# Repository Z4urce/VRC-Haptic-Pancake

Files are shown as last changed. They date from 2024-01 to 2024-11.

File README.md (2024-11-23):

# VRChat Haptic Pancake (for trackers)
A dirt cheap solution to enable haptic feedback on the Vive trackers in VRChat and Resonite.

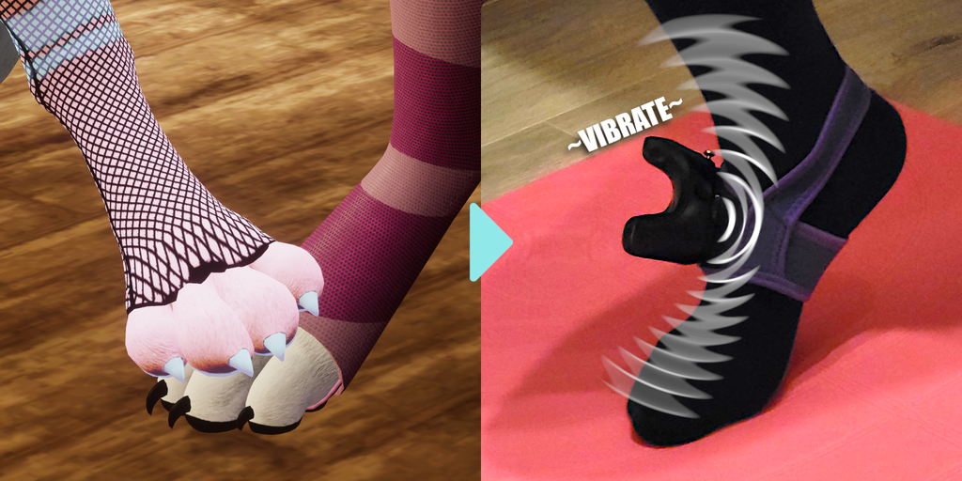
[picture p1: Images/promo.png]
[](https://youtu.be/c1JQpJwJ7_c)

# Contact

Curious about the development? Have any questions? Join the discord!



# How to make
[> Check out the Wiki for a full guide! <](https://github.com/Z4urce/VRC-Haptic-Pancake/wiki)

# Planned Features
- Support for DIY haptic devices through serial connection

# Frequently Asked Questions
- Will this harm my tracker in any way?
   - The tracking capabilities of your tracker should not get harmed at all. In case of an unexpected high load the output pin of your tracker might get fried out. That only means that in the worst case scenario you won't be able to use a vibration function on that particular tracker anymore. However after two weeks of intensive testing on my own trackers I experienced no problems whatsoever. I'll update this page if anything changes.
- Will this affect my tracking?
   - Since I implemented the vibration pattern system, it barely affects the tracking. But it still depends on the selected pattern. For example You should experience minor to no drifting with the 'Linear' one.
- Can I put the tracker elsewhere after setting up my avatar?
   - Yes. None of the trackers are permanently linked to any parts of your avatar. In fact you can even hotswap them. Just ensure you are using the right parameters in the bridge app. 
- How does this work with non-Vive trackers?
   - The software side support is guaranteed by the Haptic Pancake Bridge app. Every SteamVR compatible tracker will be recognized and external device support is imminent.
   - The hardware side is a bit more complicated:
       - For Tundra trackers you will need a custom PCB from here: [Tundra Tapper](https://github.com/nkotech/Tundra-Tapper)
       - Controllers that has been re-programmed into trackers will just work as they have haptics built in.
       - Anything else should only work if the hardware respects the SteamVR api and has built in haptics or IO to attach one.

# Support the project
<a href='https://ko-fi.com/Z4urce' target='_blank'>Buy Me a Coffee at ko-fi.com

# Special Thanks
- @BubblegumFoxxo (For helping in the testing and debugging)
- @vulp_vibes (for giving me the idea)
- @digitalf0x (for support and contributions)

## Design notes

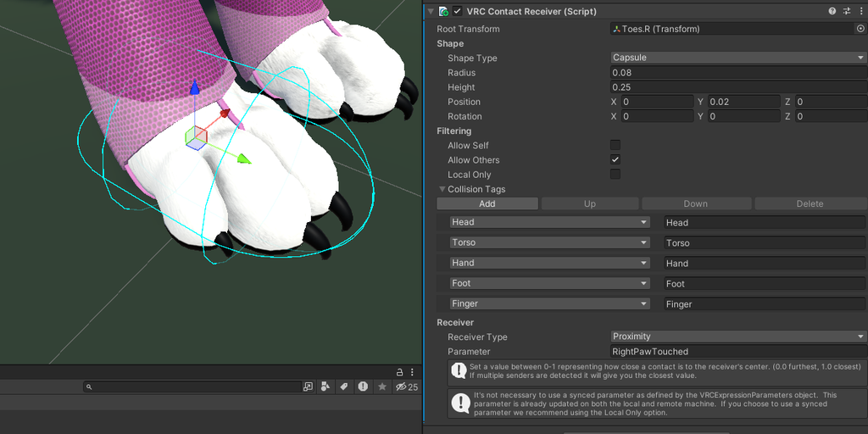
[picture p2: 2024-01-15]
Images/unity.png

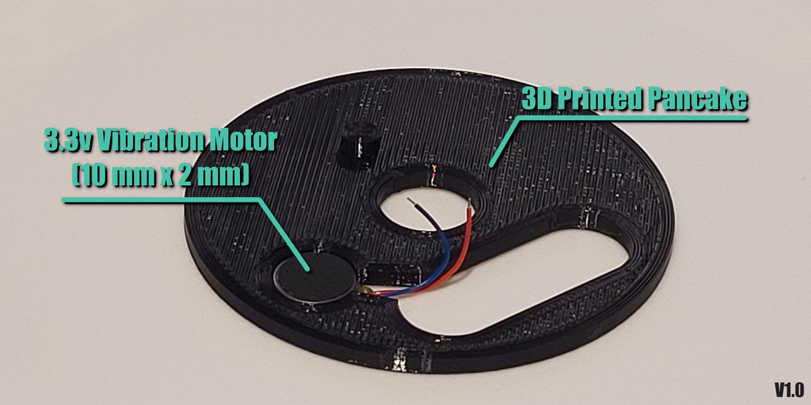
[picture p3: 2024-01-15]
Images/pancake.png

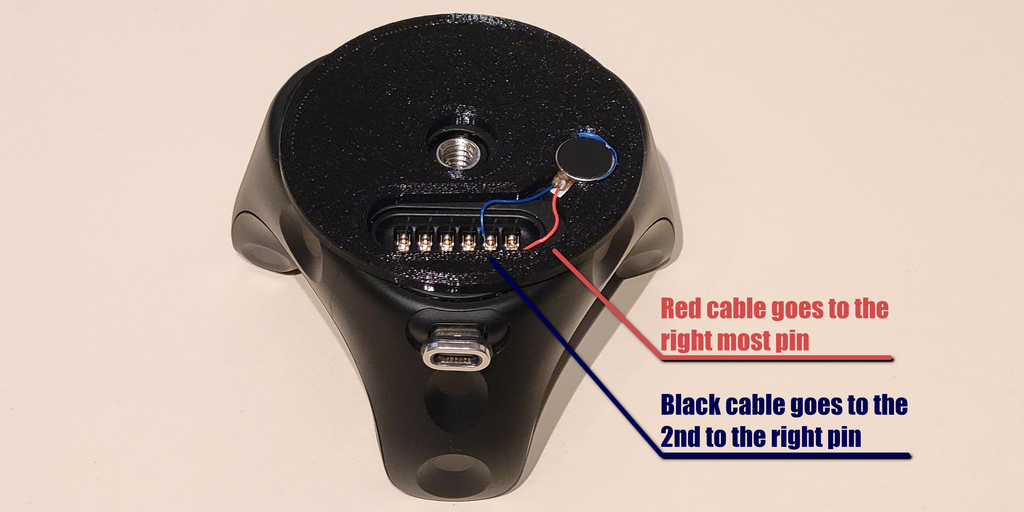
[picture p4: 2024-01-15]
Images/cable.png

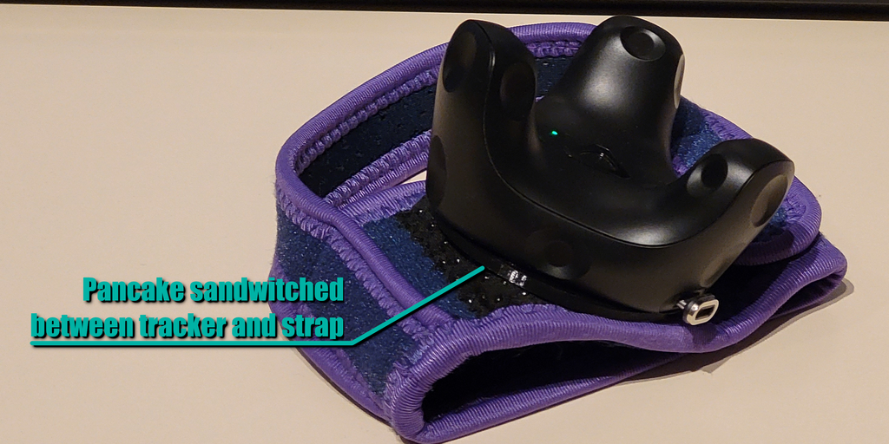
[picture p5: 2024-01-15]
Images/sandwitch.png

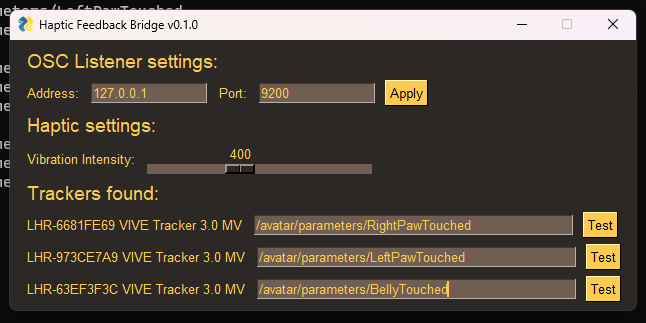
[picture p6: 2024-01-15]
Images/bridgeapp.png

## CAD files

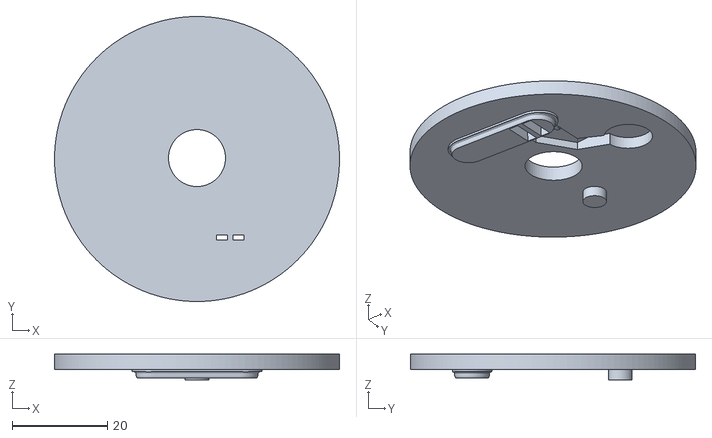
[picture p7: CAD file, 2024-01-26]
3DPrintableFiles/haptic_pancake_v2.0_M3.stl
60.0 x 60.0 x 5.45

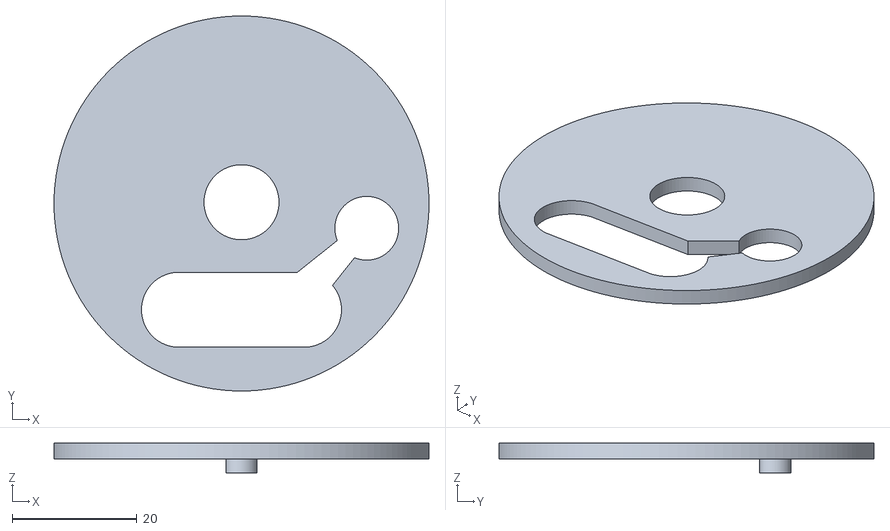
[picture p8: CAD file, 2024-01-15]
3DPrintableFiles/haptic_pancake_v1.0.stl
60.0 x 60.0 x 4.75

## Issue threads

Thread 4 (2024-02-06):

Enclosure for Tundra Tracker's IO Expansion board

digitalf0x, 2024-02-06:
## In brief
* Tundra Tracker's [IO Expansion Board](https://tundra-labs.com/products/tundra-tracker-io-expansion-board ) adds haptic options, but lacks the enclosure
   * Tundra Labs mentions [needing to customize the 3D model of the base](https://twitter.com/Tundra_Labs/status/1486802927293505536 ) to fit the haptic actuator inside
   * My 1st IO board order came with a haptic actuator, not soldered - not sure if this is standard policy

## Details
While it's possible to wire up the haptic actuator on the side and tape it somewhere, it'd be nice to integrate this with the Tundra Tracker enclosure directly.  At the time of my order, Tundra Labs shipped the right haptics actuator with the IO Expansion Board, I'd just need to solder it on.

Looking around, I've not found any existing shared 3D printable enclosures that could hold the haptics actuator.

----

I noticed your hidden `Ongoing Research` wiki page mentions this is under consideration.  If there's anything I can do to help that research, let me know.  I'm handy with electronics, though I lack a 3D printer (I can use services such as Craftcloud if needed).

This project *seems* to not be too Windows-centric, either, so I'd be happy to try to help with getting it working on Linux as part of this.

Z4urce, 2024-02-13:
Hello!
I have a discord server for research and development. [Feel free to join us!](https://discord.gg/DEWbQHqbRS)

A member of it already made the tundra's haptics work with the pancake bridge software. (With the same ERM vibration motor I recommended for the pancake)

Unfortunately I'm unable to design an enclosure for them as I don't own any. But I can help you with that if you'd like to join our cause :)

And about Linux support... I made sure the software is as multi-platform as it can be :3

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

digitalf0x, 2024-02-14:
Ah, awesome!  I imagine the enclosure will be a bit different using the haptics motor Tundra unexpectedly included with my IO board (it looks like the Switch Joycon form factor they suggest in the description, maybe it's now standard?), but that's something we can work out.

I have been pretty busy, so it will be some time until I can contribute measurements/testing/etc.  But I'll at least join the guild, and I appreciate the Linux consideration - I know it's niche to VR with Tux, but there are dozens of us :P

(I got your poke over on that IRC server, too - no worries, I got the email notification.  Though I appreciate your enthusiasm and effort to navigate a platform so few people use nowadays :sweat_smile: )

digitalf0x, 2024-03-05:
*Documenting this publicly for those following here, not on the Discord guild:*

Nearly everything works on Linux, just using the `python3 -m trace --count --coverdir=/dev/null BridgeApp/main.py` launch method to work around the segfault I experience (I updated my prior comment).

Unfortunately, Tundra Trackers seem to implement [Valve's deprecated `TriggerHapticPulse`](https://github.com/ValveSoftware/openvr/blob/v2.2.3/headers/openvr.h#L2431-L2433 ) in a way that fails to work with how VRC Haptic Pancake sends haptic pulses.

The problem might be as [described on the Steam Community forums](https://steamcommunity.com/app/358720/discussions/0/405693392914144440/ ):
> The parameter you pass into TriggerHapticPulse is measured in microseconds, with the max value (in my tests) being 3999, which is 4ms - each frame at 90Hz is 11ms long.  Because of this, if you're pulsing each frame, the effect of pulse length is felt subjectively as vibration strength.

Dropping the intensity multiplier to `10` and boosting `app_runner.py`'s `self.interval_ms = 50  # millis` to `5` milliseconds results in a partially working vibration, though the Tundra Tracker occasionally doesn't respond, blinking red, so I think I might be sending invalid commands.

(It didn't blink red when I previously put the `__pulse()` function into a while true: loop to cause it to vibrate near continuously, so I don't think it's an over-current situation.)

I'll keep looking into this as I have time to investigate.  [Maybe the `IVRInput` methods](https://github.com/ValveSoftware/openvr/blob/v2.2.3/headers/openvr.h#L5216-L5218 ) would work more consistently… if it's supported by Vive/Tundra Trackers (I recall hearing something about it only working for actual full-blown controllers, not trackers).

digitalf0x, 2024-03-08:
Doing some *very rough* experimentation, it seems like the Tundra Tracker stops responding for a short period of time if it's given too many `triggerHapticPulse()` commands (e.g. quicker than 5 ms delay), while at the same time it won't really pulse for longer than 5 ms either (possibly 3999 µs as in the Steam Community forums post linked in my prior comment).

**I do not recommend implementing the following in VR Haptic Pancake yet**, this is merely something kind of functional that I got with ~15 minutes of poking things:

Tweak to `BridgeApp/app_runner.py`:
```diff
--- BridgeApp/app_runner.py
+++ BridgeApp/app_runner.py
@@ -1,3 +1,3 @@

-        self.interval_ms = 50  # millis
+        self.interval_ms = 5  # millis
         self.interval_s = self.interval_ms / 1000  # seconds
```

And the `config.json`, prettified:
```json
{
  "version": 1,
  "server_type": 0,
  "server_ip": "127.0.0.1",
  "server_port": 9001,
  "pattern_config_list": [{
    "pattern": "Throb",
    "str_min": 0,
    "str_max": 80,
    "speed": 4
  }, {
    "pattern": "Linear",
    "str_min": 40,
    "str_max": 80,
    "speed": 16
  }],
  "tracker_config_dict": {
    "LHR-[serial-here]": {
      "enabled": true,
      "address": "/avatar/parameters/HapticsTouchWaist",
      "multiplier_override": 9.0,
      "pattern_override": "None",
      "battery_threshold": 20
    }
  },
  "tracker_to_osc": {}
}
```

This ensures that `target_ovr.py` doesn't send a pulse longer than 5 ms (might need to be 3999 µs?), as longer values seem to not actually result in longer vibration.  The below edit to `target_ovr.py` confirms this by printing a warning if you exceed that threshold.

```python
    def __pulse(self, index, pulse_length: int = 200):
        if self.is_alive():
            self.vr.triggerHapticPulse(index, 0, pulse_length)
            # HACK: test spacing out pulses
            #pulse_max_amount = 3999
            pulse_max_amount = 5000
            #sleep_min_delay = pulse_max_amount / 1000000
            #sleep_min_delay = 5000 / 1000000
            if pulse_length > pulse_max_amount:
                print("PULSE LENGTH > " + str(pulse_max_amount) + ": " + str(pulse_length))
            #while pulse_length > 3999:
            #    self.vr.triggerHapticPulse(index, 0, pulse_max_amount)
            #    pulse_length -= pulse_max_amount
            #    time.sleep(sleep_min_delay)
            #if pulse_length > 0:
            #    self.vr.triggerHapticPulse(index, 0, pulse_length)
            #    time.sleep(sleep_min_delay)
```

I got the "Identify" command to meaningfully work by uncommenting the lines to repeatedly call `triggerHapticPulse()` (and adding `import time` at the top), but doing that breaks elsewhere because the `sleep()` halts everything else.

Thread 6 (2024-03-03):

VRCOSC Modular Support

TypicalZedF, 2024-03-03:
Essentially, there is this application called [VRCOSC](https://github.com/VolcanicArts/VRCOSC). "VRCOSC is intended to act as a wrapper around VRChat's OSC system to make creating OSC programs easier, provide interfaces for other APIs and frameworks that might be useful to an OSC project, and act as a centralized source for useful OSC programs so that a user will only need to download a single application."

Essentially, I'm requesting that you port the software to work with this application so that instead of users needing to have a different application for everything, all OSC stuff including your haptic pancakes would be utilized through one application making it easier for everyone! I'm curious to see if you'll support the application as it has large numbers of users. They have documentation on how to make [Modules here](https://github.com/VolcanicArts/VRCOSC/wiki/Module-Creation).

Z4urce, 2024-03-05:
This projects will stay as a standalone application to ensure the compatibility across platforms, devices and environments.

TypicalZedF, 2024-04-25:
The Haptic Pancakes use a standard haptics system. Even Space Calibrator can cause the trackers to vibrate. I'd think it's possible to just adopt this myself to VRCOSC, and for those that wish to use it instead opposed to the python UI may.

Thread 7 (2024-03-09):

STL Print for Vive Ultimate Trackers?

JessPratson2, 2024-03-09:

Z4urce, 2024-03-14:
Waiting for a donation of Vive Ultimate trackers so I can make an STL for them as well.

TrademarkPoIicy, 2024-03-17:
I see where you are coming from needing the tracker to make sure the STL fits properly around the housing. If I had the extra money I would donate a set of trackers to you but I do not sadly. I would also like to state I am not good at CAD took one year in middle school but I can be relentless. So I have slowly started working on making housing for a haptic motor plus an easy way of connecting/disconnecting wires using screws and pogo pins combined with the ability to clip the plate that screws on a strap on the back of the tracker making there be pressure for the Pogo pins to pop into place. There is also a stl available on Vives website of the tracker. On another note, I'd like to thank you for the work that you have put in on the project and please keep up the great work.

TrademarkPoIicy, 2024-04-18:
Well this took longer than I thought it would but here it is...

[Vive_Ultimate_Tracker_Screw-On-Mount_Haptic-Pancake_ External-Wire-Crimping.zip](https://github.com/Z4urce/VRC-Haptic-Pancake/files/15021630/Vive_Ultimate_Tracker_Screw-On-Mount_Haptic-Pancake_.External-Wire-Crimping.zip)

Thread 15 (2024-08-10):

Migrate to IVRInput's haptic Actions and/or consider OpenXR?

digitalf0x, 2024-08-10:
# About that `IVRInput`…

This is the supported, modern way forward.

* Allows for frequency modulation
   * Even with ERMs instead of LRAs, offers a slightly adjustable haptics feel on Tundra Trackers
* Allows Steam to automatically map Vive/Tundra/etc Trackers with given SteamVR roles (e.g. Chest, Left Foot)
   * Haptic Pancake would just be mapping from e.g. "Chest tracker" to `/avatar/parameters/something_here`
* Solves the Tundra Tracker issue with the legacy haptics pulses being cut off, requiring 4 ms loops
* As part of this, we'll want a `.vrmanifest` file which will make the Bridge App auto-start with SteamVR, too

But.. it is an involved change.

I still don't get why `lighthouse_console`'s `haptic2` command can use the new haptics API without the need for the entire SteamVR Actions system - if we could simply copy that, then Haptic Pancake itself would need almost no changes.

**Further research on `triggerHapticVibrationAction` and how the Lighthouse console uses it is needed.**

This is a large enough project we may want to make this a v2 of Tundra Tracker support, or even a v2 of the entire Bridge App.

Considering Valve is pushing SteamVR towards OpenXR (an actually independent standard) as the replacement for OpenVR (Valve's own standard), perhaps OpenXR will provide another path forward?  It looks like [OpenXR uses the same rebindable Action system, though](https://registry.khronos.org/OpenXR/specs/1.0/man/html/xrApplyHapticFeedback.html ).

## Using `lighthouse_console`

With **SteamVR open** and your **headset connected to your PC**…

### Launching console

#### Linux

Run as your normal user:
```
$HOME/.local/share/Steam/steamapps/common/SteamVR/tools/lighthouse/bin/linux64/lighthouse_console
```

#### Windows

May need to run as administrator:
```
C:\Program Files (x86)\Steam\steamapps\common\SteamVR\tools\lighthouse\bin\win32\lighthouse_console.exe
```
(See [this HTC thread](https://forum.htc.com/topic/7413-how-to-unpair-all-controllers-peripherals-while-troubleshooting/ )

### Examples

#### Haptics help
```
lh> help
[…]
haptic [<duration_us>] [<interval_us>] [<repeat_count>] Trigger haptic pulse
haptic2 [<frequency_hz>] [<duration_ms>] [<amplitude_percent>]  Trigger haptics
[…]
```

#### Legacy API
`triggerHapticPulse()`

Some long duration (4000µs duration, 4000µs interval, 100× repeat):
```
lh> haptic 4000 4000 100
```

#### Modern API
`triggerHapticVibrationAction()`

400 Hz for 4 seconds:
```
lh> haptic2 400 4000
```

## SteamVR OpenVR API
### Legacy API (in use now)

```python
    def triggerHapticPulse(self, controllerDeviceIndex, axisId, durationMicroSec: int) -> None:
        """
        Trigger a single haptic pulse on a controller. After this call the application may not trigger another haptic pulse on this controller
        and axis combination for 5ms. This function is deprecated in favor of the new IVRInput system.
        """
        […]
```

**OpenVR says the duration is in microseconds, NOT milliseconds!**

Vive Trackers are doing something wrong.  (Perhaps they were built to an older spec, and HTC didn't want to break backwards compatibility for their enterprise customers?)  Tundra Trackers, Index Wands, etc are doing things correctly.

Tundra Trackers do have a problem with cutting off haptic pulses longer than about 4000 microseconds, though.

### Modern API (`IVRInput`)

```python
    def triggerHapticVibrationAction(self, action, startSecondsFromNow: float, durationSeconds: float, frequency: float, amplitude: float, restrictToDevice) -> None:
        """Triggers a haptic event as described by the specified action"""
        […]
```

[SteamVR now makes everything - **including haptics!** - rebindable with SteamVR Input 2.0, as per the Action manifest](https://github.com/ValveSoftware/openvr/wiki/Action-manifest ).

Haptic Pancake will no longer handle mapping to specific trackers.  This is handled by SteamVR's own UI with assigning roles to trackers.

This should allow changing tracker bindings inside SteamVR and when Haptic Pancake isn't running.

This involves a lot of haptics vibrations:
> vibration - The action is a output haptic vibration. Include one of these per type of haptic output in your application so they can be bound to different output devices if the user has them available. Examples include haptics due to firing a gun (that would usually be bound directly to a controller) or haptics from getting shot (which could be bound to a feedback vest worn on the chest).

And I think this is looking at…
1.  `def setActionManifestPath(self, actionManifestPath: str) -> None:` which will need generated according to the Valve wiki page
2.  `def getActionHandle(self, actionName: str):` on tracker load
3.  `def triggerHapticVibrationAction(self, action, [...]) -> None:` inside the Bridge App haptics loop

And to allow binding when Bridge App isn't running, and to have SteamVR auto-start the Bridge App, then we need a `.vrmanifest` file, like how WlxOverlay-S creates it - see below.

#### Other context

The whole [action manifest is the route VRCOSC went, though they're only handling controllers](https://github.com/VolcanicArts/VRCOSC/blob/main/VRCOSC.Resources/OpenVR/action_manifest.json ).

[VRC-OSC-Manager](https://github.com/DASPRiD/vrc-osc-manager ) looked interesting initially as it supports both Linux and Windows and allows multiple plugins to use one OSC input, but that entirely skips VR manifests.

#### Example config files

Adapted from [Valve's documentation](https://github.com/ValveSoftware/openvr/wiki/Action-manifest#action-manifest-file-format).
**`BridgeApp/hp_actions.json`:**
```json
{
  "default_bindings": [
   {
      "controller_type": "some_controller",
      "binding_url": "hp_bindings_fbt_trackers.json"
   }
  ],
  "actions": [
    {
      "name": "/actions/hp_haptics/out/chest",
      "requirement" : "optional",
      "type": "vibration"
    },
    {
      "name": "/actions/hp_haptics/out/foot_left",
      "requirement" : "optional",
      "type": "vibration"
    }
  ],
  "action_sets": [
    {
      "name": "/actions/hp_haptics",
      "usage": "leftright"
    }
  ],
  "localization" : [
   {
       "language_tag": "en_us",

        "/actions/hp_haptics" : "Haptics",

        "/actions/hp_haptics/out/chest" : "Touch near Chest",
        "/actions/hp_haptics/out/foot_left" : "Touch near Left Foot",

    }
  ]
}
```

Adapted [from WlxOverlay-S `actions_binding_vive.json`](https://github.com/galister/wlx-overlay-s/blob/main/src/res/actions_binding_vive.json ).
**`BridgeApp/hp_bindings_fbt_trackers.json`:**
```json
{
   "action_manifest_version" : 0,
   "app_key" : "galister.wlxoverlay-s",
   "bindings" : {
      "/actions/default": {
         "haptics": [
            {
               "output": "/actions/hp_haptics/out/chest",
               "path": "/user/[path for SteamVR's chest tracker role, e.g. 'hand/left']/output/haptic"
            },
            {
               "output": "/actions/hp_haptics/out/foot_left",
               "path": "/user/[path for SteamVR's left foot tracker role, e.g. 'hand/left']/output/haptic"
            }
         ]
      }
   },
   "category" : "steamvr_input",
   "controller_type" : "TODO_vive_controller",
   "description" : "Ver1",
   "interaction_profile" : "",
   "name" : "Haptic Pancake configuration for Full Body Trackers",
   "options" : {
      "mirror_actions" : false,
      "simulated_controller_type" : "none"
   },
   "simulated_actions" : []
}
```

Adapted [from WlxOverlay-S `openvr/manifest.rs`](https://github.com/galister/wlx-overlay-s/blob/main/src/backend/openvr/manifest.rs ).
**`BridgeApp/haptic_pancake.vrmanifest`:**
```json
{
    "source" : "builtin",
    "applications" : [
            {
                "app_key" : "z4urce.vrc-haptic-pancake",
                "launch_type" : "binary",
                "binary_path_linux" : "PATH/TO/hapticpancake",
                "binary_path_windows" : "PATH\\TO\\hapticpancake.exe",
                "is_dashboard_overlay" : false,
                "strings" : {
                    "en_us": {
                        "name" : "Haptic Pancake",
                        "description" : "A cheap solution to enable haptic feedback on full body trackers in OSC compatible games.",
                    }
                }
            }
        ]
    }
```

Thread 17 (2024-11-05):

Haptic Pancake Hotfix (v0.5.3) 's identify button doesn't seem to work correctly for TundraTracker. But latest source works correctly.

xlwnya, 2024-11-05:
I tried latest release (v0.5.3) binary and I found it's identify button doesn't vibrate the tundra tracker.

I don't know why because I tried to run Haptic Pancake from source (2024-08-20) before and it vibrate the tundra tracker correctly.

Is some regression happened to release?

I tried latest commit (011bff28b68d336e4789825fe75800894297c968) and it also works correctly.

v0.5.3 vibrates the tundra tracker 500us
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

latest source vibrates the tundra tracker 500ms
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

xlwnya, 2024-11-05:
Here is diff of my local source. (I use Japanese version of Windors and this adhoc patch fixes character set problem (My Windows can't display the "⚫" in console)
And I think this diff is not related to the problem of TundraTracker support.
```
 BridgeApp/app_gui.py | 2 +-
 1 file changed, 1 insertion(+), 1 deletion(-)

diff --git a/BridgeApp/app_gui.py b/BridgeApp/app_gui.py
index aeadc12..3aac17b 100644
--- a/BridgeApp/app_gui.py
+++ b/BridgeApp/app_gui.py
@@ -101,7 +101,7 @@ class GUIRenderer:
         return sg.Text('', font=('AnyFont', 1), auto_size_text=True)

     def tracker_row(self, tracker_id, tracker_serial, tracker_model):
-        string = f"⚫ {tracker_serial} {tracker_model}"
+        string = f"{tracker_serial} {tracker_model}"

         dev_config = self.config.get_tracker_config(tracker_serial)
         address = dev_config.address
```

digitalf0x, 2024-11-13:
I'm not sure, but I think there might be something missing from the release build uploaded to GitHub.  A friend I was helping also had the issue of the wrong pulse length.

If you can capture Python's console output on Windows, you can look for `Using 4.0 ms pulse limit workaround for […]` - if that's not there, the code isn't working either.

The commit in question is [[Update] Support Tundra Tracker with timing quirks](https://github.com/Z4urce/VRC-Haptic-Pancake/commit/8f5b5ba26c8eb711b4ec529e0dc791275b489a1b ).

xlwnya, 2024-11-13:
New release "Haptic Pancake (v0.6.0a)" vibrate the tundra tracker correctly!
It's fixed.
Thank you!

Closed 2024-11-13.

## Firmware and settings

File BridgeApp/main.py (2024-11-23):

from app_config import AppConfig
from app_gui import GUIRenderer
from server_base import ServerBase
from server_osc import VRChatOSCReceiver
from server_websocket import ResoniteWebSocketServer
from target_ovr import OpenVRTracker
import traceback
import platform

bridge_server: ServerBase = None
vr: OpenVRTracker = None
config: AppConfig = None
gui: GUIRenderer = None
external_id: int = 0


def main():
    print(f"[Main] Using Python: {platform.python_version()}")
    print("[Main] Starting up...")
    # Load the config
    global config
    config = AppConfig.load()
    config.check_integrity()
    config.save()
    print("[Main] Config loaded")

    # Init GUI
    global gui
    gui = GUIRenderer(config, pulse_test, restart_bridge_server, refresh_tracker_list, add_external_target)
    print("[Main] GUI initialized")

    # Start the Server
    start_bridge_server()

    print("[Main] Bridge server started")

    # Init OpenVR
    global vr
    vr = OpenVRTracker(config)

    # Add trackers to GUI
    refresh_tracker_list()

    # Add footer
    gui.add_footer()

    # Main GUI loop here
    while gui.run():
        pass


def start_bridge_server():
    global bridge_server
    if config.server_type == 1:
        bridge_server = ResoniteWebSocketServer(config, param_received, gui.update_osc_status_bar)
    else:
        bridge_server = VRChatOSCReceiver(config, param_received, gui.update_osc_status_bar)
    bridge_server.start_server()


# Adapter functions
def pulse_test(tracker_serial):
    print(f"[Main] Pulse test for {tracker_serial} executed.")
    vr.pulse_by_serial(tracker_serial, 500)
    # param_received("TEST", 1.0)


def restart_bridge_server():
    if bridge_server is not None:
        bridge_server.shutdown()
    start_bridge_server()


def refresh_tracker_list():
    if vr is None or gui is None:
        return

    for device in vr.query_devices():
        gui.add_tracker(device.serial, device.model)

    # Debug tracker (Uncomment this for debug purposes)
    # gui.add_tracker("T35T-53R1AL", "Test Model 1.0")
    print("[Main] Tracker list refreshed")


def add_external_target(external_type):
    global external_id
    external_id += 1
    print(external_type + '; ' + str(external_id))

    sound_emu = "EMUSND"
    text_emu = "EMUTXT"
    serial_com = "SERIALCOM"
    network = "NETWORK"
    serial = "-"+str(external_id)

    if external_type.endswith(sound_emu):
        gui.add_external_device(sound_emu+serial, "Sound Target")
    if external_type.endswith(text_emu):
        gui.add_external_device(text_emu+serial, "Text Target")
    if external_type.endswith(serial_com):
        gui.add_external_device(serial_com+serial, "Serial Target")
    if external_type.endswith(network):
        gui.add_external_device(network+serial, "Network Target")


def param_received(address, value):
    # value is the floating value (0..1) that determines how intense the feedback should be
    for serial, tracker_config in config.tracker_config_dict.items():
        if  address in tracker_config.address_list:
            vr.set_strength(serial, value)


if __name__ == '__main__':
    try:
        main()
        if config is not None:
            config.save()
    except Exception as e:
        print(f"[Main][ERROR] {e}\n{traceback.format_exc()}")
        with open('hpb_crashlog.txt', "w+") as crash_log:
            import json

            json.dump(traceback.format_exc(), fp=crash_log)
    finally:
        # Shut down the processes
        print("[Main] Halting...")
        if bridge_server is not None:
            bridge_server.shutdown()

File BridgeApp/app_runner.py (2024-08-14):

import threading
import time
from app_pattern import VibrationPattern
from app_config import AppConfig, VRTracker


class FeedbackThread(threading.Thread):
    LOW_BATTERY_ALERT_COUNT = 8

    def __init__(self, config: AppConfig, tracker: VRTracker, pulse_function, battery_function):
        super().__init__()
        self.config = config
        self.tracker = tracker
        self.pulse_function = pulse_function
        self.battery_function = battery_function

        self.tracker_config = config.get_tracker_config(tracker.serial)

        self.battery_low_notif = self.LOW_BATTERY_ALERT_COUNT

        self.strength: float = 0.0  # Should be treated as a value between 0 and 1
        self.strength_delta: float = 0.0
        self.last_str_set_time = time.time()

        # Some devices (e.g. Tundra Trackers) use microseconds instead of
        # milliseconds for the legacy triggerHapticPulse() function, but then
        # limit you to around 3999µs per pulse.
        #
        # TODO: That number is probably not exact; check with an oscilloscope.
        #
        # See https://steamcommunity.com/app/358720/discussions/0/405693392914144440/
        #
        # In these situations, the update loop needs to run much faster to
        # try to avoid exceeding the maximum duration of one haptic pulse.
        # Exceeding 100% strength requires extending a pulse into the next loop
        # iteration.  Any manual pulses also need to be spread out over time to
        # not exceed the limit.
        #
        # TODO: Try switching from "triggerHapticPulse()" to IVRInput
        # triggerHapticPulse() is deprecated as per Valve:
        # * https://github.com/ValveSoftware/openvr/blob/v2.2.3/headers/openvr.h#L2431-L2433
        # * https://github.com/ValveSoftware/openvr/blob/v2.2.3/headers/openvr.h#L5216-L5218
        #
        # This might be specific to Tundra Trackers vs. Vive Trackers, as
        # Tundra ships their IO Expansion board with a LRA/haptic actuator

        # Assume trackers that behave as expected
        self.interval_ms = 50  # millis

        # HACK: multiplier to convert from milliseconds to the device time unit
        self.hack_pulse_mult_to_ms = 0
        # HACK: maximum allowed pulse duration in milliseconds
        # Exceeding the limit likely results in sporadic or glitchy vibration
        # instead of a max strength (as continuous as possible) pulse.
        self.hack_pulse_limit_ms = 0
        # HACK: if true, the warning for a pulse exceeding the pulse limit has
        # been shown.  Only shown once to avoid console spam.
        self.hack_pulse_limit_exceeded = False
        # HACK: when to stop a queued force pulse
        self.hack_pulse_force_stop_time = 0

        # Special-case as needed
        if self.tracker.model.startswith("Tundra"):
            # Tundra Tracker
            # Works in microseconds
            self.hack_pulse_mult_to_ms = 1 / 1000
            # Has a limit of roughly 4000 microseconds
            self.hack_pulse_limit_ms = 4000 * self.hack_pulse_mult_to_ms

        if self.hack_pulse_limit_ms > 0:
            # Apply pulse duration hack/workaround
            self.interval_ms = self.hack_pulse_limit_ms
            print(f"[VibrationManager] Using {self.interval_ms} ms pulse limit workaround for {self.tracker.serial}")

        self.interval_s = self.interval_ms / 1000  # seconds

        self.vp = VibrationPattern(self.config)

    def set_strength(self, strength):
        try:
            strength = float(strength)
        except ValueError:
            strength = 0.0

        self.strength_delta += abs(strength - self.strength)
        self.strength = strength
        self.last_str_set_time = time.time()

    def run(self):
        print(f"[VibrationManager] Thread started for {self.tracker.serial}")

        while True:
            start_time = time.time()

            pulse_length = 0

            strength = self.calculate_strength(start_time)
            if strength > 0:
                # So we pulse every self.interval_ms (e.g. 50) ms.  That means a
                # self.interval_ms (50/etc) ms pulse would be 100%.
                pulse_length = strength * self.interval_ms
                # Don't cap strength to 1.0 as velocity calculation can easily
                # exceed 1.  Also, some may rely on overriding the multiplier
                # to adjust for different timescales, etc.

            # Check if there's a queued force pulse
            if start_time < self.hack_pulse_force_stop_time:
                # Convert to milliseconds
                # (Don't cap this so if a pulse limit is specified, the
                #  leftover pulse carries over.)
                force_pulse_duration = (self.hack_pulse_force_stop_time - start_time) * 1000
                # Pick the biggest number for pulse_length
                pulse_length = max(pulse_length, force_pulse_duration)

            # If a maximum pulse length is specified...
            if self.hack_pulse_limit_ms > 0:
                # ...and we exceed it...
                if pulse_length > self.hack_pulse_limit_ms:
                    if not self.hack_pulse_limit_exceeded:
                        print(f"[VibrationManager] {round(pulse_length, 2)} ms pulse exceeds {self.interval_ms} ms limit for {self.tracker.serial}, extending next pulse [this warning won't repeat]")
                        self.hack_pulse_limit_exceeded = True

                    # Carry over any excess to the next loop iteration by
                    # queuing it as a forced pulse.  Don't subtract anything as
                    # this pulse's time.sleep() also reduces the next pulse.
                    self.force_pulse(pulse_length)
                    # Do a max length pulse now
                    pulse_length = self.hack_pulse_limit_ms

            # Convert to target unit of time if necessary
            if self.hack_pulse_mult_to_ms:
                pulse_length = pulse_length / self.hack_pulse_mult_to_ms

            # Convert to integer (after all else for max precision)
            pulse_length = int(pulse_length)

            # Trigger pulse if nonzero length requested
            if pulse_length > 0:
                self.pulse_function(self.tracker.index, pulse_length)

            sleep = max(self.interval_s - (time.time() - start_time), 0.0)
            time.sleep(sleep)

    def calculate_strength(self, start_time):
        # Check the battery threshold
        if self.battery_function(self.tracker.index) < (self.tracker_config.battery_threshold / 100):
            if self.battery_low_notif > 0:
                self.battery_low_notif -= 1
                return self.battery_low_notif % .9
            return 0
        self.battery_low_notif = self.LOW_BATTERY_ALERT_COUNT
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

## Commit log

2024-01-15 [Update] Reorganized
    [haptic_pancake_v1.0.stl, motor_socket.blend]
2024-01-17 [Fix] Error on exit
    [gui.py, main.py, osc.py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]
2024-01-18 [Update] Dynamic tracker loading and vibration patterns
    [config.py, gui.py, main.py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]
2024-01-26 [Add] M3 pancake
    [haptic_pancake_v2.0_M3.stl]
2024-01-27 [Update] Added Velocity, Velocity Approaching, VelocityPlusProximity patterns
2024-02-05 [Update]
    - Bool and int is now acceptable OSC param
    - Standalone Proximity vs Velocity pattern system
    - Preparations for Resonite and Serial compatibility and
2024-02-06 Planned features for the upcoming versions:
    Resonite support (WebSockets)
    PWM Emulation for vibration motors (Real difference between 40% and 60% vibration)
    Minimal battery threshold for the trackers (Vibration can be disabled bellow)
    Tracker calibration (A wizard will help you calibrate the tracker's haptics, to achieve the best results)
    [app_config.py, app_gui.py, app_pattern.py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]
2024-02-12 [FIx] iterating through dict items
    [main.py]
2024-02-17 [Fix] Haptics not triggering when colliders align
    [app_runner.py]
2024-03-02 [Fix] Identify button now applies the predefined multipliers to Tundra trackers and Vive controllers
    [app_gui.py, app_runner.py, main.py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]
2024-03-11 [Init] Option to add device
2024-03-20 [Fix] target_ovr: Assume 100% if missing battery
    Assume 100% battery charge (1.0) if missing the battery percentage
    float.
    This fixes some devices (e.g. Tundra Trackers) that don't immediately
    report their battery status, especially when at 100% charge.
    Skip intermediate variables and return the value directly.
    [target_ovr.py]
2024-03-29 [Fix] ci: Allow manual builds, shorten name
    Allow triggering manual builds in case dependencies change, artifacts
    expire or get deleted, etc.
    Shorten the workflow name to "Build PyInstall" to be easier to read
    on GitHub's mobile site.
    See https://docs.github.com/en/actions/using-workflows/manually-running-a-workflow
2024-07-08 [Update] Switch to FreeSimpleGUI, update deps
    Switch from PySimpleGUI to FreeSimpleGUI, avoiding the phone-home
    license checking and hassle of expecting everyone to register a
    hobbyist license key once a year.
    See https://www.reddit.com/r/Python/comments/1d8d4iv/psa_pysimplegui_has_deleted_almost_all_old_lgpl/
    And https://github.com/spyoungtech/FreeSimpleGUI
    Updates to Py/FreeSimpleGUI now check for invalid updates to the GUI
    once a window is closed and pop up a dialog box instead of letting the
    exception occur as expected. Add a "shutting_down" check to stop
    text updates once closing the main window.
    See https://docs.pysimplegui.com/en/latest/cookbook/original/exception_handling/
    Updat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
    [app_gui.py]
2024-07-11 gui: Fix spinbox ranges to include maximum value
    Set range of intensity spinboxes to 0-100 via range(0, 101).
    Python treats range(0, 5) as [0, 1, 2, 3, 4], verifiable with...
    > [num for num in range(0, 5)]
    This fixes the maximum strength being limited to 99%.
    [app_gui.py]
2024-07-11 [Update] Support Tundra Tracker with timing quirks
    Support the Tundra Tracker (Haptic Tundrakes?) via…
    1. Microseconds instead of milliseconds for "triggerHapticPulse()"
    Scale up from milliseconds via a time-based multiplier for the legacy,
    deprecated "triggerHapticPulse()" method.
    Set Tundra Trackers back to a multiplier of 1.0 elsewhere, matching
    the behavior of Vive Trackers.
    This could be replaced with support for the IVRInput system instead of
    using the deprecated triggerHapticPulse() function.
    2. Limit pulse length to 4000 µs / 4 ms
    Tundra Trackers have a limit of around 4000 µs (4 ms) per pulse, so
    the update loop must run more frequently to stay within that maximum
    durati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
    [app_config.py, app_gui.py, app_runner.py]
2024-11-09 [Fix] deps: Add setuptools for running from source
    Add "setuptools" to requirements.txt for running the BridgeApp from
    source code in a Python Virtual Environment. This fixes OpenVR
    raising an error when running on Python 3.12 with Kubuntu 24.04.
    See https://setuptools.pypa.io/en/latest/userguide/quickstart.html
    Example error:
    Traceback (most recent call last):
    File "[...]/VRC-Haptic-Pancake/BridgeApp/main.py", line 6, in <module>
    from target_ovr import OpenVRTracker
    File "[...]/VRC-Haptic-Pancake/BridgeApp/target_ovr.py", line 1, in <module>
    import openvr
    File "[...]/ignored-from-repo-venv/lib/python3.12/site-packages/openvr/__init__.py", line 8, in <module>
    import pkg_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
